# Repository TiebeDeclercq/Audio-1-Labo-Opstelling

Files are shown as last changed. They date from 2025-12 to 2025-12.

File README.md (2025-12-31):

# Audio1-Labo-Opstelling

Complete printplaat met alle schakelingen voor audio 1 en vermogenelektronica @Vives kortrijk.
Met een printbare voet voor betere stabiliteit en geen kortsluiting te krijgen.
Op deze voet wordt er gewerkt met heated inserts (M3) voor het monteren van de print.

De printplaat bevat een Klasse A versterker in twee-traps configuratie met Darlington uitgang. Daarnaast is er een Klasse AB versterker met push-pull configuratie en diode bias die werkt op dual supply spanning.
Voor frequentie-analyse zijn er twee circuits: een BJT common emitter configuratie en een JFET common source configuratie, beide met bypass mogelijkheden. Alle belangrijke signalen zijn toegankelijk via testpunten en connectors.

Assembled PCB

Het schema is als volgt:

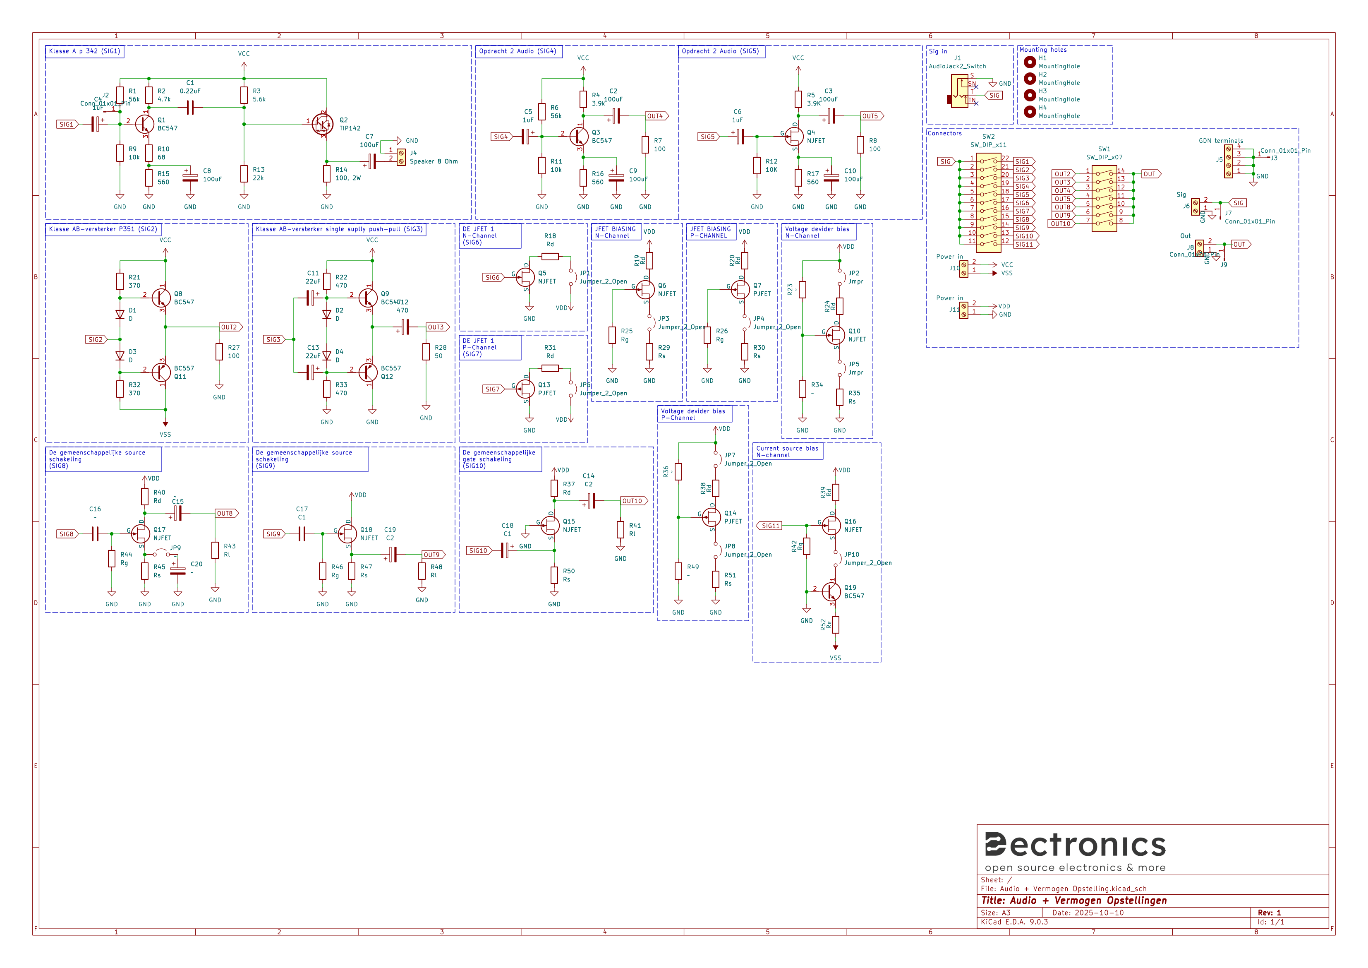
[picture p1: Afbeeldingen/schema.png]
Schema


Voor het solderen kan je gebruikmaken van de meegeleverde BOM file, de printplaat is een mix van SMD en TH componenten.

Assembled PCB

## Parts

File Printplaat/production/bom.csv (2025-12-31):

Designator | Footprint | Quantity | Value | LCSC Part #
C1 | 0805 | 1 | 0.22uF
C10, C15, C16, C2, C20, C3, C5, C6, C9 | CP_Axial_L11.0mm_D5.0mm_P18.00mm_Horizontal | 9 | ~
C11, C13 | CP_Axial_L11.0mm_D5.0mm_P18.00mm_Horizontal | 2 | 22uF
C12 | CP_Axial_L11.0mm_D5.0mm_P18.00mm_Horizontal | 1 | 470
C14, C19 | CP_Axial_L11.0mm_D5.0mm_P18.00mm_Horizontal | 2 | C2
C17, C18 | CP_Axial_L11.0mm_D5.0mm_P18.00mm_Horizontal | 2 | C1
C4 | CP_Elec_4x5.4 | 1 | 1uF
C7, C8 | CP_Elec_6.3x5.4 | 2 | 100uF
D1, D2, D3, D4 | D_DO-15_P15.24mm_Horizontal | 4 | D
J1 | Jack_3.5mm_KoreanHropartsElec_PJ-320D-4A_Horizontal | 1 | AudioJack2_Switch
J10, J11 | TerminalBlock_Phoenix_MKDS-1,5-2_1x02_P5.00mm_Horizontal | 2 | Power in
J2, J3, J7, J9 | PinHeader_1x01_P2.54mm_Vertical | 4 | Conn_01x01_Pin
J4 | TerminalBlock_Phoenix_MKDS-1,5-2_1x02_P5.00mm_Horizontal | 1 | Speaker 8 Ohm
J5 | TerminalBlock_Phoenix_MKDS-1,5-4-5.08_1x04_P5.08mm_Horizontal | 1 | GDN terminals
J6 | TerminalBlock_Phoenix_MKDS-1,5-2_1x02_P5.00mm_Horizontal | 1 | Sig
J8 | TerminalBlock_Phoenix_MKDS-1,5-2_1x02_P5.00mm_Horizontal | 1 | Out
JP1, JP10, JP3, JP4, JP6, JP7, JP8 | PinHeader_1x02_P2.54mm_Vertical | 7 | Jumper_2_Open
JP2, JP5 | PinHeader_1x02_P2.54mm_Vertical | 2 | Jmpr
JP9 | PinHeader_1x02_P2.54mm_Vertical | 1 | ~
Q1, Q19, Q3, Q8, Q9 | TO-92_Inline | 5 | BC547
Q10, Q15, Q16, Q17, Q18, Q4, Q5, Q6 | TRANS_J109 | 8 | NJFET
Q11, Q12 | TO-92_Inline | 2 | BC557
Q13, Q14, Q7 | SOT23 | 3 | PJFET
Q2 | TO-220-3_Horizontal_TabDown | 1 | TIP142
R1 | 0805 | 1 | 56k
R10 | 0805 | 1 | 68
R11, R23, R34, R36, R49, R6 | R_Axial_DIN0207_L6.3mm_D2.5mm_P10.16mm_Horizontal | 6 | ~
R12, R25, R26, R42, R44, R46 | R_Axial_DIN0207_L6.3mm_D2.5mm_P10.16mm_Horizontal | 6 | Rg
R13 | 0805 | 1 | 22k
R14 | 2512 | 1 | 33, 2W
R15 | 0805 | 1 | 560
R16, R52 | R_Axial_DIN0207_L6.3mm_D2.5mm_P10.16mm_Horizontal | 2 | Re
R17, R29, R30, R35, R45, R47, R50, R51 | R_Axial_DIN0207_L6.3mm_D2.5mm_P10.16mm_Horizontal | 8 | Rs
R18, R19, R20, R24, R31, R37, R38, R39, R40, R5 | R_Axial_DIN0207_L6.3mm_D2.5mm_P10.16mm_Horizontal | 10 | Rd
R2 | 0805 | 1 | 4.7k
R21, R32 | R_Axial_DIN0207_L6.3mm_D2.5mm_P10.16mm_Horizontal | 2 | 430
R22, R33 | R_Axial_DIN0207_L6.3mm_D2.5mm_P10.16mm_Horizontal | 2 | 470
R27 | R_Axial_DIN0207_L6.3mm_D2.5mm_P10.16mm_Horizontal | 1 | 16
R28 | R_Axial_DIN0207_L6.3mm_D2.5mm_P10.16mm_Horizontal | 1 | 50
R3 | 0805 | 1 | 5.6k
R4 | R_Axial_DIN0207_L6.3mm_D2.5mm_P10.16mm_Horizontal | 1 | Rc
R41, R43, R48, R7, R8 | R_Axial_DIN0207_L6.3mm_D2.5mm_P10.16mm_Horizontal | 5 | Rl
R9 | 0805 | 1 | 10k
SW1 | SW_DIP_SPSTx07_Slide_9.78x19.96mm_W7.62mm_P2.54mm | 1 | SW_DIP_x07
SW2 | SW_DIP_SPSTx11_Slide_9.78x30.12mm_W7.62mm_P2.54mm | 1 | SW_DIP_x11

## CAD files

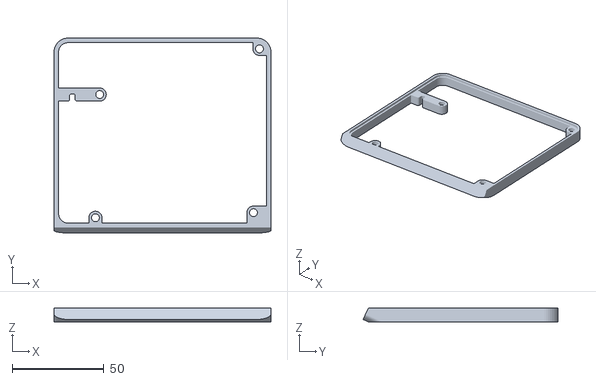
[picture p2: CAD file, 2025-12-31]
Printfiles/Houder.obj
118.3 x 106.3 x 7.51

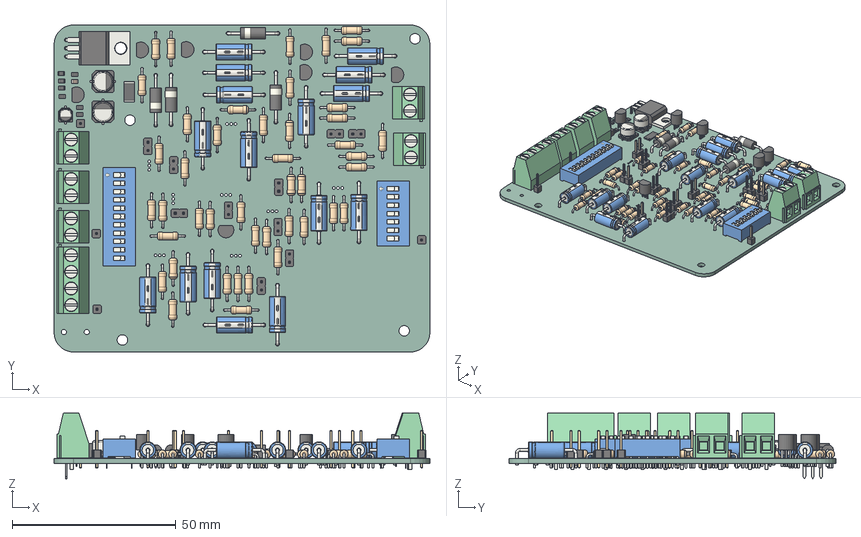
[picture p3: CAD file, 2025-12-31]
Printplaat/Audio + Vermogen Opstelling.step
114.9 x 100.0 x 20.1 mm
CP_Axial_L11.0mm_D5.0mm_P18.00mm_Horizontal x 16
R_Axial_DIN0207_L6.3mm_D2.5mm_P10.16mm_Horizontal x 44
R_0805_2012Metric x 7
SW_DIP_SPSTx11_Slide_9.78x30.12mm_W7.62mm_P2.54mm
PinHeader_1x02_P2.54mm_Vertical x 10
TO-92_Inline x 7
D_DO-15_P15.24mm_Horizontal x 4
R_2512_6332Metric
C_0805_2012Metric
PinHeader_1x01_P2.54mm_Vertical x 4
TO-220-3_Horizontal_TabDown
TerminalBlock_Phoenix_MKDS-1,5-2_1x02_P5.00mm_Horizontal x 5
SW_DIP_SPSTx07_Slide_9.78x19.96mm_W7.62mm_P2.54mm
CP_Elec_6.3x5.4 x 2
TerminalBlock_Phoenix_MKDS-1,5-4-5.08_1x04_P5.08mm_Horizontal
CP_Elec_4x5.4
Audio + Vermogen Opstelling_PCB

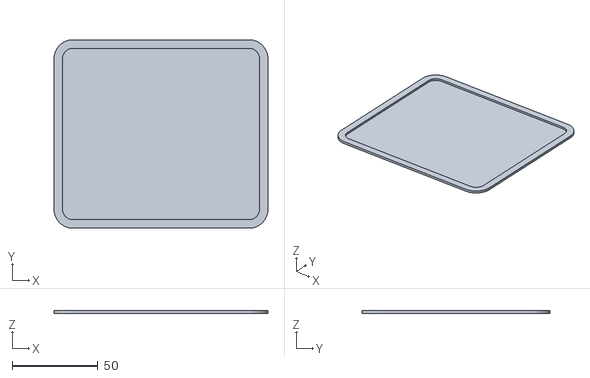
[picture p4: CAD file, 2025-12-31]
Printplaat/Stencil/bottomStencil.stl
125.1 x 110.2 x 1.50

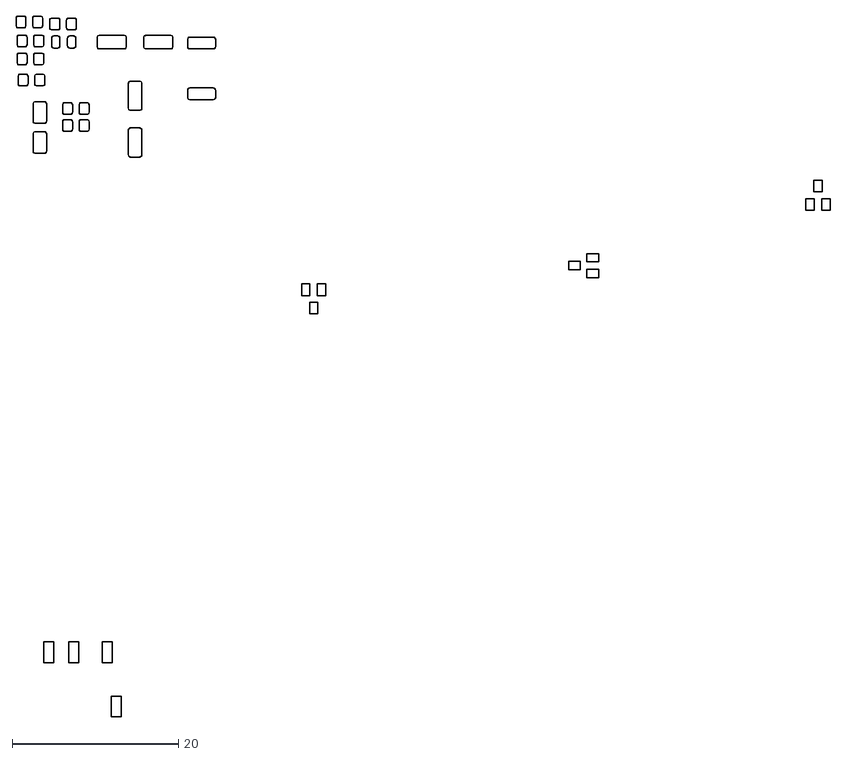
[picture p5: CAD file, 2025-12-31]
Printplaat/Stencil/Audio + Vermogen Opstelling-PasteTop.dxf
97.8 x 84.2

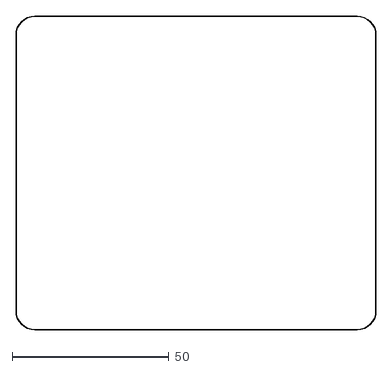
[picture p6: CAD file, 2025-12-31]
Printplaat/Stencil/Audio + Vermogen Opstelling-EdgeCuts.dxf
114.9 x 100.0

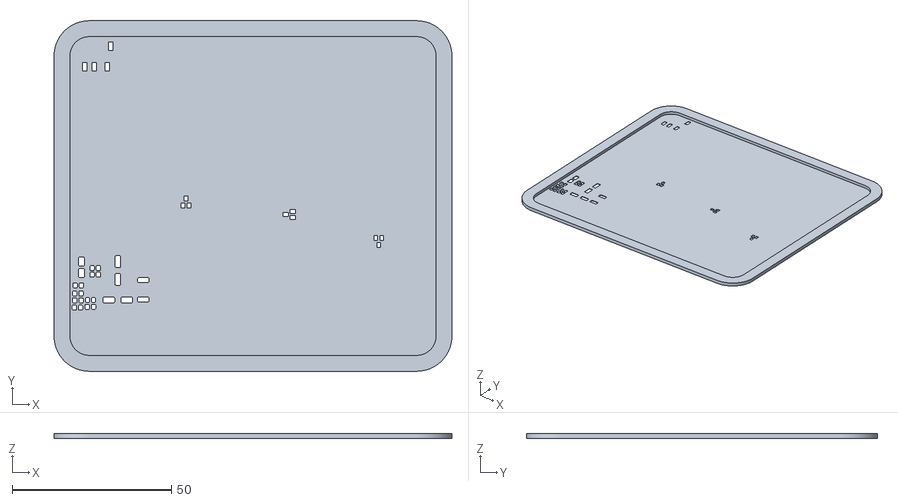
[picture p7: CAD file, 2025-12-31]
Printplaat/Stencil/topStencil.stl
125.1 x 110.2 x 1.50

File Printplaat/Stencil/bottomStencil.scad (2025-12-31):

// Generated by SolidPython 1.1.3 on 2025-11-13 14:27:48
$fa = 0.4; $fs = 0.4;


rotate(a = 0, v = [1, 0, 0]) {
	difference() {
		scale(v = [1, 1, 1]) {
			difference() {
				linear_extrude(height = 1.5000000000) {
					offset(r = 5.1000000000) {
						import(file = "C:/Users/tiebe/Desktop/Electronics/School/Patje zuig men kloten/Audio + Vermogen Opstelling/Stencil/Audio + Vermogen Opstelling-EdgeCuts.dxf", origin = [0, 0]);
					}
				}
				translate(v = [0, 0, 0.2000000000]) {
					linear_extrude(height = 1.5000000000) {
						offset(r = 0.1000000000) {
							import(file = "C:/Users/tiebe/Desktop/Electronics/School/Patje zuig men kloten/Audio + Vermogen Opstelling/Stencil/Audio + Vermogen Opstelling-EdgeCuts.dxf", origin = [0, 0]);
						}
					}
				}
			}
		}
		linear_extrude(center = true, height = 0.8000000000) {
			offset(chamfer = false, delta = 0.1000000000) {
				import(file = "C:/Users/tiebe/Desktop/Electronics/School/Patje zuig men kloten/Audio + Vermogen Opstelling/Stencil/Audio + Vermogen Opstelling-PasteBottom.dxf", origin = [0, 0]);
			}
		}
	}
}
/***********************************************
*********      SolidPython code:      **********
************************************************
 
from pcbnewTransition import pcbnew
import numpy as np
import json
from collections import OrderedDict
from kikit.common import *
from kikit.defs import *
from kikit.substrate import Substrate, extractRings, toShapely, linestringToKicad
from kikit.export import gerberImpl, pasteDxfExport
from kikit.export import exportSettingsJlcpcb
import solid
import solid.utils
import subprocess
import shutil
from kikit.common import removeComponents, parseReferences

from shapely.geometry import Point


OUTER_BORDER = fromMm(7.5)
INNER_BORDER = fromMm(5)
MOUNTING_HOLES_COUNT = 3
MOUNTING_HOLE_R = fromMm(1)
HOLE_SPACING = fromMm(20)

def addBottomCounterpart(board, item):
    item = item.Duplicate()
    item.SetLayer(Layer.B_Paste)
    board.Add(item)

def addRoundedCorner(board, center, start, end, thickness):
    corner = pcbnew.PCB_SHAPE()
    corner.SetShape(STROKE_T.S_ARC)
    corner.SetCenter(toKiCADPoint((center[0], center[1])))
    corner.SetStart(toKiCADPoint((start[0], start[1])))

    if np.cross(start - center, end - center) > 0:
        corner.SetArcAngleAndEnd(fromDegrees(90), True)
    else:
        corner.SetArcAngleAndEnd(fromDegrees(-90), True)
    corner.SetWidth(thickness)
    corner.SetLayer(Layer.F_Paste)
    board.Add(corner)
    addBottomCounterpart(board, corner)

def addLine(board, start, end, thickness):
    line = pcbnew.PCB_SHAPE()
    line.SetShape(STROKE_T.S_SEGMENT)
    line.SetStart(toKiCADPoint((start[0], start[1])))
    line.SetEnd(toKiCADPoint((end[0], end[1])))
    line.SetWidth(thickness)
    line.SetLayer(Layer.F_Paste)
    board.Add(line)
    addBottomCounterpart(board, line)

def addBite(board, origin, direction, normal, thickness):
    """
    Adds a bite to the stencil, direction points to the bridge, normal points
    inside the stencil
    """
    direction = normalize(direction) * thickness
    normal = normalize(normal) * thickness
    center = toKiCADPoint((origin[0], origin[1])) + toKiCADPoint((normal[0], normal[1]))
    start = origin
    end = center + toKiCADPoint((direction[0], direction[1]))
    # addLine(board, end, end + normal / 2, thickness)
    addRoundedCorner(board, center, start, end, thickness)

def numberOfCuts(length, bridgeWidth, bridgeSpacing):
    """
    Return number of bridges which fit inside the length and cut length
    """
    count = int(np.floor((length + bridgeWidth) / (bridgeWidth + bridgeSpacing)))
    cutLength = (length - (count - 1) * bridgeWidth) / count
    return count, cutLength

def addFrame(board, rect, bridgeWidth, bridgeSpacing, clearance):
    """
    Add rectangular frame to the board
    """
    R=fromMm(1)

    corners = [
        (tl(rect), toKiCADPoint((R, 0)), toKiCADPoint((0, R))), # TL
        (tr(rect), toKiCADPoint((0, R)), toKiCADPoint((-R, 0))), # TR
        (br(rect), toKiCADPoint((-R, 0)), toKiCADPoint((0, -R))), # BR
        (bl(rect), toKiCADPoint((0, -R)), toKiCADPoint((R, 0))) # BL
    ]
    for c, sOffset, eOffset in corners:
        addRoundedCorner(board, c + sOffset + eOffset, c + sOffset, c + eOffset, clearance)

    count, cutLength = numberOfCuts(rect.GetWidth() - 2 * R, bridgeWidth, bridgeSpacing)
    for i in range(count):
        start = rect.GetX() + R + i * bridgeWidth + i * cutLength
        end = start + cutLength

        y1, y2 = rect.GetY(), rect.GetY() + rect.GetHeight()
        addLine(board, toKiCADPoint((start, y1)), toKiCADPoint((end, y1)), clearance)
        if i != 0:
            addBite(board, toKiCADPoint((start, y1)), toKiCADPoint((-1, 0)), toKiCADPoint((0, 1)), clearance)
        if i != count - 1:
            addBite(board, toKiCADPoint((end, y1)), toKiCADPoint((1, 0)), toKiCADPoint((0, 1)), clearance)
        addLine(board, toKiCADPoint((start, y2)), toKiCADPoint((end, y2)), clearance)
        if i != 0:
            addBite(board, toKiCADPoint((start, y2)), toKiCADPoint((-1, 0)), toKiCADPoint((0, -1)), clearance)
        if i != count - 1:
            addBite(board, toKiCADPoint((end, y2)), toKiCADPoint((1, 0)), toKiCADPoint((0, -1)), clearance)

    count, cutLength = numberOfCuts(rect.GetHeight() - 2 * R, bridgeWidth, bridgeSpacing)
    for i in range(count):
        start = rect.GetY() + R + i * bridgeWidth + i * cutLength
        end = start + cutLength

        x1, x2 = rect.GetX(), rect.GetX() + rect.GetWidth()
        addLine(board, toKiCADPoint((x1, start)), toKiCADPoint((x1, end)), clearance)
        if i != 0:
            addBite(board, toKiCADPoint((x1, start)), toKiCADPoint((0, -1)), toKiCADPoint((1, 0)), clearance)
        if i != count - 1:
            addBite(board, toKiCADPoint((x1, end)), toKiCADPoint((0, 1)), toKiCADPoint((1, 0)), clearance)
        addLine(board, toKiCADPoint((x2, start)), toKiCADPoint((x2, end)), clearance)
        if i != 0:
            addBite(board, toKiCADPoint((x2, start)), toKiCADPoint((0, -1)), toKiCADPoint((-1, 0)), clearance)
        if i != count - 1:
            addBite(board, toKiCADPoint((x2, end)), toKiCADPoint((0, 1)), toKiCADPoint((-1, 0)), clearance)

def addHole(board, position, radius):
    circle = pcbnew.PCB_SHAPE()
    circle.SetShape(STROKE_T.S_CIRCLE)
    circle.SetCenter(toKiCADPoint((position[0], position[1])))
    # Set 3'oclock point of the circle to set radius
    circle.SetEnd(toKiCADPoint((position[0], position[1])) + toKiCADPoint((radius/2, 0)))

    circle.SetWidth(radius)
    circle.SetLayer(Layer.F_Paste)
    board.Add(circle)
    addBottomCounterpart(board, circle)

def addJigFrame(board, jigFrameSize, bridgeWidth=fromMm(2),
                bridgeSpacing=fromMm(10), clearance=fromMm(0.5)):
    """
    Given a Pcbnew board finds the board outline and creates a stencil for
    KiKit's stencil jig.

    Mainly, adds mounting holes and mouse bites to define the panel outline.

    jigFrameSize is a tuple (width, height).
    """
    bBox = findBoardBoundingBox(board)
    frameSize = rectByCenter(rectCenter(bBox),
        jigFrameSize[0] + 2 * (OUTER_BORDER + INNER_BORDER),
        jigFrameSize[1] + 2 * (OUTER_BORDER + INNER_BORDER))
    cutSize = rectByCenter(rectCenter(bBox),
        jigFrameSize[0] + 2 * (OUTER_BORDER + INNER_BORDER) - fromMm(1),
        jigFrameSize[1] + 2 * (OUTER_BORDER + INNER_BORDER) - fromMm(1))
    addFrame(board, cutSize, bridgeWidth, bridgeSpacing, clearance)

    for i in range(MOUNTING_HOLES_COUNT):
        x = frameSize.GetX() + OUTER_BORDER / 2 + (i + 1) * (frameSize.GetWidth() - OUTER_BORDER) / (MOUNTING_HOLES_COUNT + 1)
        addHole(board, toKiCADPoint((x, OUTER_BORDER / 2 + frameSize.GetY())), MOUNTING_HOLE_R)
        addHole(board, toKiCADPoint((x, - OUTER_BORDER / 2 +frameSize.GetY() + frameSize.GetHeight())), MOUNTING_HOLE_R)
    for i in range(MOUNTING_HOLES_COUNT):
        y = frameSize.GetY() + OUTER_BORDER / 2 + (i + 1) * (frameSize.GetHeight() - OUTER_BORDER) / (MOUNTING_HOLES_COUNT + 1)
        addHole(board, toKiCADPoint((OUTER_BORDER / 2 + frameSize.GetX(), y)), MOUNTING_HOLE_R)
        addHole(board, toKiCADPoint((- OUTER_BORDER / 2 +frameSize.GetX() + frameSize.GetWidth(), y)), MOUNTING_HOLE_R)

    PIN_TOLERANCE = fromMm(0.05)
    addHole(board, tl(frameSize) + toKiCADPoint((OUTER_BORDER / 2, OUTER_BORDER / 2)), MOUNTING_HOLE_R + PIN_TOLERANCE)
    addHole(board, tr(frameSize) + toKiCADPoint((-OUTER_BORDER / 2, OUTER_BORDER / 2)), MOUNTING_HOLE_R + PIN_TOLERANCE)
    addHole(board, br(frameSize) + toKiCADPoint((-OUTER_BORDER / 2, -OUTER_BORDER / 2)), MOUNTING_HOLE_R + PIN_TOLERANCE)
    addHole(board, bl(frameSize) + toKiCADPoint((OUTER_BORDER / 2, -OUTER_BORDER / 2)), MOUNTING_HOLE_R + PIN_TOLERANCE)
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

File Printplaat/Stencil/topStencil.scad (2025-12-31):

// Generated by SolidPython 1.1.3 on 2025-11-13 14:27:49
$fa = 0.4; $fs = 0.4;


rotate(a = 180, v = [1, 0, 0]) {
	difference() {
		scale(v = [1, 1, -1]) {
			difference() {
				linear_extrude(height = 1.5000000000) {
					offset(r = 5.1000000000) {
						import(file = "C:/Users/tiebe/Desktop/Electronics/School/Patje zuig men kloten/Audio + Vermogen Opstelling/Stencil/Audio + Vermogen Opstelling-EdgeCuts.dxf", origin = [0, 0]);
					}
				}
				translate(v = [0, 0, 0.2000000000]) {
					linear_extrude(height = 1.5000000000) {
						offset(r = 0.1000000000) {
							import(file = "C:/Users/tiebe/Desktop/Electronics/School/Patje zuig men kloten/Audio + Vermogen Opstelling/Stencil/Audio + Vermogen Opstelling-EdgeCuts.dxf", origin = [0, 0]);
						}
					}
				}
			}
		}
		linear_extrude(center = true, height = 0.8000000000) {
			offset(chamfer = false, delta = 0.1000000000) {
				import(file = "C:/Users/tiebe/Desktop/Electronics/School/Patje zuig men kloten/Audio + Vermogen Opstelling/Stencil/Audio + Vermogen Opstelling-PasteTop.dxf", origin = [0, 0]);
			}
		}
	}
}
/***********************************************
*********      SolidPython code:      **********
************************************************
 
from pcbnewTransition import pcbnew
import numpy as np
import json
from collections import OrderedDict
from kikit.common import *
from kikit.defs import *
from kikit.substrate import Substrate, extractRings, toShapely, linestringToKicad
from kikit.export import gerberImpl, pasteDxfExport
from kikit.export import exportSettingsJlcpcb
import solid
import solid.utils
import subprocess
import shutil
from kikit.common import removeComponents, parseReferences

from shapely.geometry import Point


OUTER_BORDER = fromMm(7.5)
INNER_BORDER = fromMm(5)
MOUNTING_HOLES_COUNT = 3
MOUNTING_HOLE_R = fromMm(1)
HOLE_SPACING = fromMm(20)

def addBottomCounterpart(board, item):
    item = item.Duplicate()
    item.SetLayer(Layer.B_Paste)
    board.Add(item)

def addRoundedCorner(board, center, start, end, thickness):
    corner = pcbnew.PCB_SHAPE()
    corner.SetShape(STROKE_T.S_ARC)
    corner.SetCenter(toKiCADPoint((center[0], center[1])))
    corner.SetStart(toKiCADPoint((start[0], start[1])))

    if np.cross(start - center, end - center) > 0:
        corner.SetArcAngleAndEnd(fromDegrees(90), True)
    else:
        corner.SetArcAngleAndEnd(fromDegrees(-90), True)
    corner.SetWidth(thickness)
    corner.SetLayer(Layer.F_Paste)
    board.Add(corner)
    addBottomCounterpart(board, corner)

def addLine(board, start, end, thickness):
    line = pcbnew.PCB_SHAPE()
    line.SetShape(STROKE_T.S_SEGMENT)
    line.SetStart(toKiCADPoint((start[0], start[1])))
    line.SetEnd(toKiCADPoint((end[0], end[1])))
    line.SetWidth(thickness)
    line.SetLayer(Layer.F_Paste)
    board.Add(line)
    addBottomCounterpart(board, line)

def addBite(board, origin, direction, normal, thickness):
    """
    Adds a bite to the stencil, direction points to the bridge, normal points
    inside the stencil
    """
    direction = normalize(direction) * thickness
    normal = normalize(normal) * thickness
    center = toKiCADPoint((origin[0], origin[1])) + toKiCADPoint((normal[0], normal[1]))
    start = origin
    end = center + toKiCADPoint((direction[0], direction[1]))
    # addLine(board, end, end + normal / 2, thickness)
    addRoundedCorner(board, center, start, end, thickness)

def numberOfCuts(length, bridgeWidth, bridgeSpacing):
    """
    Return number of bridges which fit inside the length and cut length
    """
    count = int(np.floor((length + bridgeWidth) / (bridgeWidth + bridgeSpacing)))
    cutLength = (length - (count - 1) * bridgeWidth) / count
    return count, cutLength

def addFrame(board, rect, bridgeWidth, bridgeSpacing, clearance):
    """
    Add rectangular frame to the board
    """
    R=fromMm(1)

    corners = [
        (tl(rect), toKiCADPoint((R, 0)), toKiCADPoint((0, R))), # TL
        (tr(rect), toKiCADPoint((0, R)), toKiCADPoint((-R, 0))), # TR
        (br(rect), toKiCADPoint((-R, 0)), toKiCADPoint((0, -R))), # BR
        (bl(rect), toKiCADPoint((0, -R)), toKiCADPoint((R, 0))) # BL
    ]
    for c, sOffset, eOffset in corners:
        addRoundedCorner(board, c + sOffset + eOffset, c + sOffset, c + eOffset, clearance)

    count, cutLength = numberOfCuts(rect.GetWidth() - 2 * R, bridgeWidth, bridgeSpacing)
    for i in range(count):
        start = rect.GetX() + R + i * bridgeWidth + i * cutLength
        end = start + cutLength

        y1, y2 = rect.GetY(), rect.GetY() + rect.GetHeight()
        addLine(board, toKiCADPoint((start, y1)), toKiCADPoint((end, y1)), clearance)
        if i != 0:
            addBite(board, toKiCADPoint((start, y1)), toKiCADPoint((-1, 0)), toKiCADPoint((0, 1)), clearance)
        if i != count - 1:
            addBite(board, toKiCADPoint((end, y1)), toKiCADPoint((1, 0)), toKiCADPoint((0, 1)), clearance)
        addLine(board, toKiCADPoint((start, y2)), toKiCADPoint((end, y2)), clearance)
        if i != 0:
            addBite(board, toKiCADPoint((start, y2)), toKiCADPoint((-1, 0)), toKiCADPoint((0, -1)), clearance)
        if i != count - 1:
            addBite(board, toKiCADPoint((end, y2)), toKiCADPoint((1, 0)), toKiCADPoint((0, -1)), clearance)

    count, cutLength = numberOfCuts(rect.GetHeight() - 2 * R, bridgeWidth, bridgeSpacing)
    for i in range(count):
        start = rect.GetY() + R + i * bridgeWidth + i * cutLength
        end = start + cutLength

        x1, x2 = rect.GetX(), rect.GetX() + rect.GetWidth()
        addLine(board, toKiCADPoint((x1, start)), toKiCADPoint((x1, end)), clearance)
        if i != 0:
            addBite(board, toKiCADPoint((x1, start)), toKiCADPoint((0, -1)), toKiCADPoint((1, 0)), clearance)
        if i != count - 1:
            addBite(board, toKiCADPoint((x1, end)), toKiCADPoint((0, 1)), toKiCADPoint((1, 0)), clearance)
        addLine(board, toKiCADPoint((x2, start)), toKiCADPoint((x2, end)), clearance)
        if i != 0:
            addBite(board, toKiCADPoint((x2, start)), toKiCADPoint((0, -1)), toKiCADPoint((-1, 0)), clearance)
        if i != count - 1:
            addBite(board, toKiCADPoint((x2, end)), toKiCADPoint((0, 1)), toKiCADPoint((-1, 0)), clearance)

def addHole(board, position, radius):
    circle = pcbnew.PCB_SHAPE()
    circle.SetShape(STROKE_T.S_CIRCLE)
    circle.SetCenter(toKiCADPoint((position[0], position[1])))
    # Set 3'oclock point of the circle to set radius
    circle.SetEnd(toKiCADPoint((position[0], position[1])) + toKiCADPoint((radius/2, 0)))

    circle.SetWidth(radius)
    circle.SetLayer(Layer.F_Paste)
    board.Add(circle)
    addBottomCounterpart(board, circle)

def addJigFrame(board, jigFrameSize, bridgeWidth=fromMm(2),
                bridgeSpacing=fromMm(10), clearance=fromMm(0.5)):
    """
    Given a Pcbnew board finds the board outline and creates a stencil for
    KiKit's stencil jig.

    Mainly, adds mounting holes and mouse bites to define the panel outline.

    jigFrameSize is a tuple (width, height).
    """
    bBox = findBoardBoundingBox(board)
    frameSize = rectByCenter(rectCenter(bBox),
        jigFrameSize[0] + 2 * (OUTER_BORDER + INNER_BORDER),
        jigFrameSize[1] + 2 * (OUTER_BORDER + INNER_BORDER))
    cutSize = rectByCenter(rectCenter(bBox),
        jigFrameSize[0] + 2 * (OUTER_BORDER + INNER_BORDER) - fromMm(1),
        jigFrameSize[1] + 2 * (OUTER_BORDER + INNER_BORDER) - fromMm(1))
    addFrame(board, cutSize, bridgeWidth, bridgeSpacing, clearance)

    for i in range(MOUNTING_HOLES_COUNT):
        x = frameSize.GetX() + OUTER_BORDER / 2 + (i + 1) * (frameSize.GetWidth() - OUTER_BORDER) / (MOUNTING_HOLES_COUNT + 1)
        addHole(board, toKiCADPoint((x, OUTER_BORDER / 2 + frameSize.GetY())), MOUNTING_HOLE_R)
        addHole(board, toKiCADPoint((x, - OUTER_BORDER / 2 +frameSize.GetY() + frameSize.GetHeight())), MOUNTING_HOLE_R)
    for i in range(MOUNTING_HOLES_COUNT):
        y = frameSize.GetY() + OUTER_BORDER / 2 + (i + 1) * (frameSize.GetHeight() - OUTER_BORDER) / (MOUNTING_HOLES_COUNT + 1)
        addHole(board, toKiCADPoint((OUTER_BORDER / 2 + frameSize.GetX(), y)), MOUNTING_HOLE_R)
        addHole(board, toKiCADPoint((- OUTER_BORDER / 2 +frameSize.GetX() + frameSize.GetWidth(), y)), MOUNTING_HOLE_R)

    PIN_TOLERANCE = fromMm(0.05)
    addHole(board, tl(frameSize) + toKiCADPoint((OUTER_BORDER / 2, OUTER_BORDER / 2)), MOUNTING_HOLE_R + PIN_TOLERANCE)
    addHole(board, tr(frameSize) + toKiCADPoint((-OUTER_BORDER / 2, OUTER_BORDER / 2)), MOUNTING_HOLE_R + PIN_TOLERANCE)
    addHole(board, br(frameSize) + toKiCADPoint((-OUTER_BORDER / 2, -OUTER_BORDER / 2)), MOUNTING_HOLE_R + PIN_TOLERANCE)
    addHole(board, bl(frameSize) + toKiCADPoint((OUTER_BORDER / 2, -OUTER_BORDER / 2)), MOUNTING_HOLE_R + PIN_TOLERANCE)
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

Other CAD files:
Printplaat/Stencil/Audio + Vermogen Opstelling-PasteBottom.dxf

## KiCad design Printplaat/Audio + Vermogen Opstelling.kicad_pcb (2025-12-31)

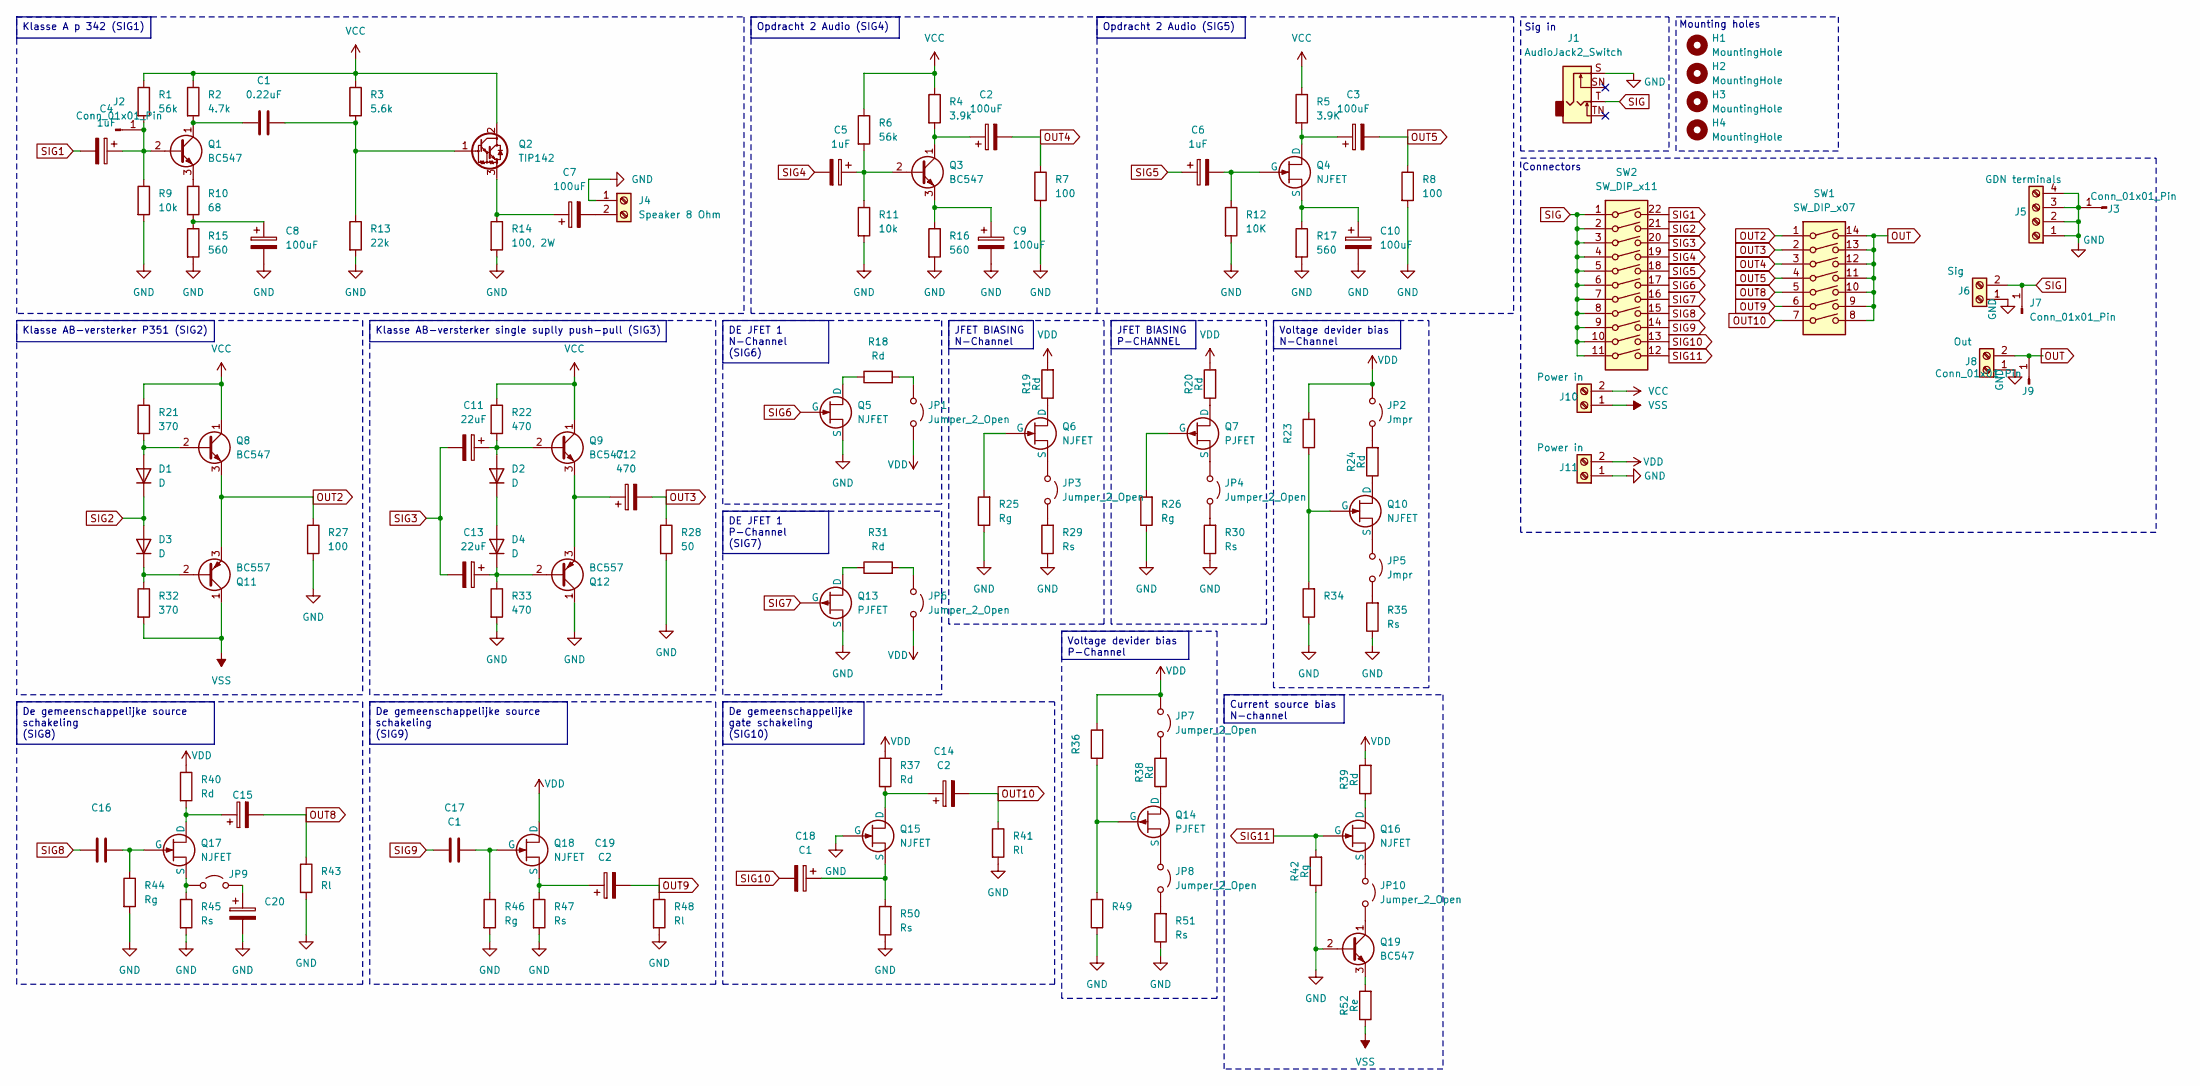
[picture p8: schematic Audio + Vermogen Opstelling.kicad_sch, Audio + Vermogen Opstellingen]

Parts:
C1: 0.22uF; C_0805_2012Metric
C2, C3, C9, C10: 100uF; CP_Axial_L11.0mm_D5.0mm_P18.00mm_Horizontal
C4: 1uF; CP_Elec_4x5.4
C5, C6: 1uF; CP_Axial_L11.0mm_D5.0mm_P18.00mm_Horizontal
C7, C8: 100uF; CP_Elec_6.3x5.4
C11, C13: 22uF; CP_Axial_L11.0mm_D5.0mm_P18.00mm_Horizontal
C12: 470; CP_Axial_L11.0mm_D5.0mm_P18.00mm_Horizontal
C14, C19: C2; CP_Axial_L11.0mm_D5.0mm_P18.00mm_Horizontal
C15, C16, C20: CP_Axial_L11.0mm_D5.0mm_P18.00mm_Horizontal
C17, C18: C1; CP_Axial_L11.0mm_D5.0mm_P18.00mm_Horizontal
D1, D2, D3, D4: D; D_DO-15_P15.24mm_Horizontal
H1, H2, H3, H4: MountingHole; MountingHole_3.2mm_M3
J1: AudioJack2_Switch; Jack_3.5mm_KoreanHropartsElec_PJ-320D-4A_Horizontal
J2, J3, J7, J9: Conn_01x01_Pin; PinHeader_1x01_P2.54mm_Vertical
J4: Speaker 8 Ohm; TerminalBlock_Phoenix_MKDS-1,5-2_1x02_P5.00mm_Horizontal
J5: GDN terminals; TerminalBlock_Phoenix_MKDS-1,5-4-5.08_1x04_P5.08mm_Horizont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
J6: Sig; TerminalBlock_Phoenix_MKDS-1,5-2_1x02_P5.00mm_Horizontal
J8: Out; TerminalBlock_Phoenix_MKDS-1,5-2_1x02_P5.00mm_Horizontal
J10, J11: Power in; TerminalBlock_Phoenix_MKDS-1,5-2_1x02_P5.00mm_Horizontal
JP1, JP3, JP4, JP6, JP7, JP8, JP10: Jumper_2_Open; PinHeader_1x02_P2.54mm_Vertical
JP2, JP5: Jmpr; PinHeader_1x02_P2.54mm_Vertical
JP9: PinHeader_1x02_P2.54mm_Vertical
Q1, Q3, Q8, Q9, Q19: BC547; TO-92_Inline
Q2: TIP142; TO-220-3_Horizontal_TabDown
Q4, Q5, Q6, Q10, Q15, Q16, Q17, Q18: NJFET; TRANS_J109
Q7, Q13, Q14: PJFET; SOT23
Q11, Q12: BC557; TO-92_Inline
R1: 56k; R_0805_2012Metric_Pad1.20x1.40mm_HandSolder
R2: 4.7k; R_0805_2012Metric_Pad1.20x1.40mm_HandSolder
R3: 5.6k; R_0805_2012Metric_Pad1.20x1.40mm_HandSolder
R4: 3.9k; R_Axial_DIN0207_L6.3mm_D2.5mm_P10.16mm_Horizontal
R5: 3.9K; R_Axial_DIN0207_L6.3mm_D2.5mm_P10.16mm_Horizontal
R6: 56k; R_Axial_DIN0207_L6.3mm_D2.5mm_P10.16mm_Horizontal
R7, R8, R27: 100; R_Axial_DIN0207_L6.3mm_D2.5mm_P10.16mm_Horizontal
R9: 10k; R_0805_2012Metric_Pad1.20x1.40mm_HandSolder
R10: 68; R_0805_2012Metric_Pad1.20x1.40mm_HandSolder
R11: 10k; R_Axial_DIN0207_L6.3mm_D2.5mm_P10.16mm_Horizontal
R12: 10K; R_Axial_DIN0207_L6.3mm_D2.5mm_P10.16mm_Horizontal
R13: 22k; R_0805_2012Metric_Pad1.20x1.40mm_HandSolder
R14: 100, 2W; R_2512_6332Metric_Pad1.40x3.35mm_HandSolder
R15: 560; R_0805_2012Metric_Pad1.20x1.40mm_HandSolder
R16, R17: 560; R_Axial_DIN0207_L6.3mm_D2.5mm_P10.16mm_Horizontal
R18, R19, R20, R24, R31, R37, R38, R39, R40: Rd; R_Axial_DIN0207_L6.3mm_D2.5mm_P10.16mm_Horizontal
R21, R32: 370; R_Axial_DIN0207_L6.3mm_D2.5mm_P10.16mm_Horizontal
R22, R33: 470; R_Axial_DIN0207_L6.3mm_D2.5mm_P10.16mm_Horizontal
R23, R34, R36, R49: R_Axial_DIN0207_L6.3mm_D2.5mm_P10.16mm_Horizontal
R25, R26, R42, R44, R46: Rg; R_Axial_DIN0207_L6.3mm_D2.5mm_P10.16mm_Horizontal
R28: 50; R_Axial_DIN0207_L6.3mm_D2.5mm_P10.16mm_Horizontal
R29, R30, R35, R45, R47, R50, R51: Rs; R_Axial_DIN0207_L6.3mm_D2.5mm_P10.16mm_Horizontal
R41, R43, R48: Rl; R_Axial_DIN0207_L6.3mm_D2.5mm_P10.16mm_Horizontal
R52: Re; R_Axial_DIN0207_L6.3mm_D2.5mm_P10.16mm_Horizontal
SW1: SW_DIP_x07; SW_DIP_SPSTx07_Slide_9.78x19.96mm_W7.62mm_P2.54mm
SW2: SW_DIP_x11; SW_DIP_SPSTx11_Slide_9.78x30.12mm_W7.62mm_P2.54mm

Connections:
GND: C8.2, C9.2, C10.2, C20.2, J1.S, J3.1, J4.1, J5.1, J5.2, J5.3, J5.4, J6.1, J8.1, J11.1, Q5.3 (S), Q12.1 (C), Q13.3 (S), Q15.2 (G), Q19.2 (B), R7.2, R8.2, R9.2, R11.2, R12.2, R13.2, R14.2, R15.2, R16.2, R17.2, R25.1, R26.1, R27.2, R28.2, R29.1, R30.1, R33.2, R34.1, R35.1, R41.2, R42.1, R43.2, R44.2, R45.2, R46.2, R47.2, R48.2, R49.1, R50.1, R51.1
unnamed: C8.1, R10.2, R15.1
unnamed: D1.2 (A), Q8.2 (B), R21.2
unnamed: C11.1, D2.2 (A), Q9.2 (B), R22.2
unnamed: D2.1 (K), D4.2 (A)
unnamed: D3.1 (K), Q11.2 (B), R32.1
unnamed: C13.1, D4.1 (K), Q12.2 (B), R33.1
unnamed: C4.1, J2.1, Q1.2 (B), R1.2, R9.1
unnamed: C7.2, J4.2
unnamed: JP1.1 (A), R18.2
unnamed: JP2.2 (B), R24.2
unnamed: JP3.1 (A), Q6.3 (S)
unnamed: JP3.2 (B), R29.2
unnamed: JP4.1 (A), Q7.3 (S)
unnamed: JP4.2 (B), R30.2
unnamed: JP5.1 (A), Q10.3 (S)
unnamed: JP5.2 (B), R35.2
unnamed: JP6.1 (A), R31.2
unnamed: JP7.2 (B), R38.2
unnamed: JP8.1 (A), Q14.3 (S)
unnamed: JP8.2 (B), R51.2
unnamed: JP9.1 (A), Q17.3 (S), R45.1
unnamed: C20.1, JP9.2 (B)
unnamed: JP10.1 (A), Q16.3 (S)
unnamed: JP10.2 (B), Q19.1 (C)
unnamed: C1.1, Q1.1 (C), R2.2
unnamed: Q1.3 (E), R10.1
unnamed: C1.2, Q2.1 (B), R3.2, R13.1
unnamed: C7.1, Q2.3 (E), R14.1
unnamed: C5.1, Q3.2 (B), R6.2, R11.1
unnamed: C2.1, Q3.1 (C), R4.2
unnamed: C9.1, Q3.3 (E), R16.1
unnamed: C3.1, Q4.1 (D), R5.2
unnamed: C6.2, Q4.2 (G), R12.1
unnamed: C10.1, Q4.3 (S), R17.1
unnamed: Q5.1 (D), R18.1
unnamed: Q6.1 (D), R19.1
unnamed: Q6.2 (G), R25.2
unnamed: Q7.1 (D), R20.1
unnamed: Q7.2 (G), R26.2
unnamed: Q10.1 (D), R24.1
unnamed: Q10.2 (G), R23.1, R34.2
unnamed: C12.1, Q9.3 (E), Q12.3 (E)
unnamed: Q13.1 (D), R31.1
unnamed: Q14.1 (D), R38.1
unnamed: Q14.2 (G), R36.1, R49.2
unnamed: C14.1, Q15.1 (D), R37.1
unnamed: C18.1, Q15.3 (S), R50.2
unnamed: Q16.1 (D), R39.1
unnamed: C15.1, Q17.1 (D), R40.2
unnamed: C16.2, Q17.2 (G), R44.1
unnamed: C17.2, Q18.2 (G), R46.1
unnamed: C19.1, Q18.3 (S), R47.1
unnamed: Q19.3 (E), R52.2
OUT: J8.2, J9.1, SW1.8, SW1.9, SW1.10, SW1.11, SW1.12, SW1.13, SW1.14
OUT2: Q8.3 (E), Q11.3 (E), R27.1, SW1.1
OUT3: C12.2, R28.1, SW1.2
OUT4: C2.2, R7.1, SW1.3
OUT5: C3.2, R8.1, SW1.4
OUT8: C15.2, R43.1, SW1.5
OUT9: C19.2, R48.1, SW1.6
OUT10: C14.2, R41.1, SW1.7
SIG: J1.T, J6.2, J7.1, SW2.1, SW2.2, SW2.3, SW2.4, SW2.5, SW2.6, SW2.7, SW2.8, SW2.9, SW2.10, SW2.11
SIG1: C4.2, SW2.22
SIG2: D1.1 (K), D3.2 (A), SW2.21
SIG3: C11.2, C13.2, SW2.20
SIG4: C5.2, SW2.19
SIG5: C6.1, SW2.18
SIG6: Q5.2 (G), SW2.17
SIG7: Q13.2 (G), SW2.16
SIG8: C16.1, SW2.15
SIG9: C17.1, SW2.14
SIG10: C18.2, SW2.13
SIG11: Q16.2 (G), R42.2, SW2.12
VCC: J10.2, Q2.2 (C), Q8.1 (C), Q9.1 (C), R1.1, R2.1, R3.1, R4.1, R5.1, R6.1, R21.1, R22.1
VDD: J11.2, JP1.2 (B), JP2.1 (A), JP6.2 (B), JP7.1 (A), Q18.1 (D), R19.2, R20.2, R23.2, R36.2, R37.2, R39.2, R40.1
VSS: J10.1, Q11.1 (C), R32.2, R52.1

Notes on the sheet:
Sig in
Connectors
Mounting holes
DE JFET 1 N-Channel (SIG6)
Klasse AB-versterker single suplly push-pull (SIG3)
De gemeenschappelijke source schakeling (SIG9)
Current source bias N-channel
DE JFET 1 P-Channel (SIG7)
Opdracht 2 Audio (SIG5)
Opdracht 2 Audio (SIG4)
Klasse AB-versterker P351 (SIG2)
De gemeenschappelijke source schakeling (SIG8)
JFET BIASING N-Channel
Voltage devider bias N-Channel
Voltage devider bias P-Channel
Klasse A p 342 (SIG1)
JFET BIASING P-CHANNEL
De gemeenschappelijke gate schakeling (SIG10)

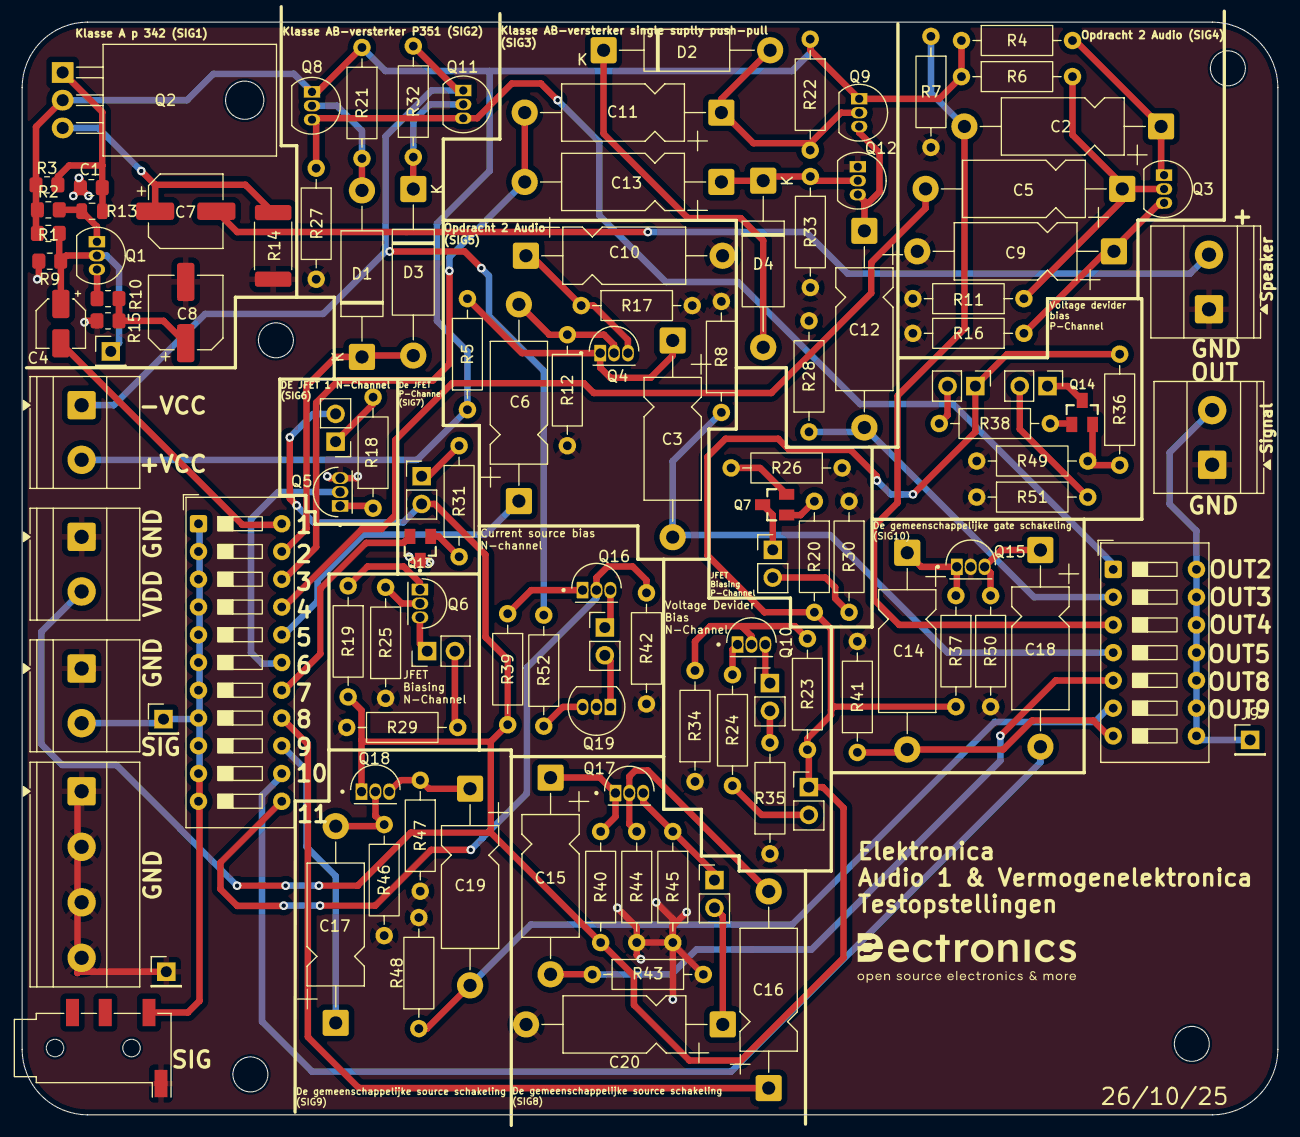
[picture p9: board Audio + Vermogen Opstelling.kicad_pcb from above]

Board: 2 copper layers, 114.9 x 100.0 mm, 122 parts (0 on the bottom side), 77 nets.
